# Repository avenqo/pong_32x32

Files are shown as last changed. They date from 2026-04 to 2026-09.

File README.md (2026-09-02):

## PöNG 32x32

**PöNG 32x32** is a project that serves as a platform for implementing various games.

The key components include:

- ESP32 controller
- A display based on a 32 × 32 RGB LED matrix,
- Two joysticks for player input,
- Multiple displays,
- A matrix display for showing game status information,
- A 16×2 LCD display with a rotary encoder for navigating the system menu.

Additionally, an SD card reader is integrated, which can be used, for example, to display graphics.

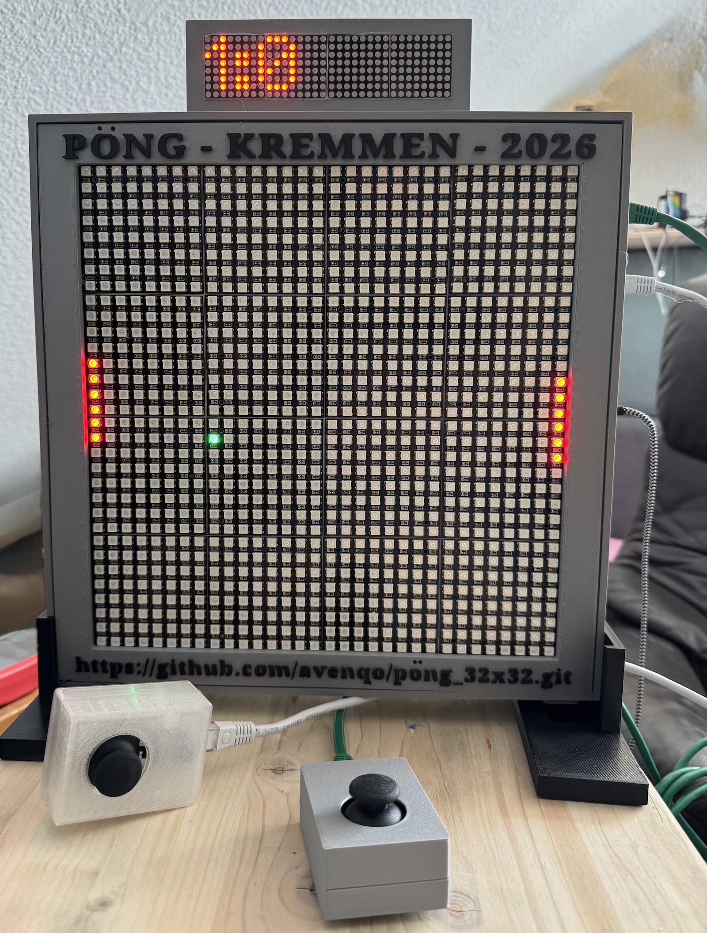
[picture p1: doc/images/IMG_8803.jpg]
Pöng32 Optional


The project consists of documentation for:

- [Hardware](doc/hardware.md),
- 3D models for the [Casing](doc/casing.md) and individual components,
- The actual [Software](doc/software.md), as well as several smaller test programs.

Inspired by the classic game Pong, I implemented a similar game to demonstrate the capabilities of the platform - **PöNG 32x32**.

### Game Operating Instructions

After power-on the device shows a short `START` splash and then runs in
*demo mode*: both paddles are controlled by the built-in AI, so the machine
plays against itself.

Switch between demo and a real match with the rotary encoder:

- turn the encoder while the menu shows `Mode`, or
- give the encoder a medium press (about a second).

Turning back to `Mode` (or another medium press) ends the match and returns to
demo mode. Holding the encoder long **twice within 4 seconds** restarts the
device (the first long press only shows a confirmation).

The system menu is opened with a short encoder press, which cycles through
`Mode`, `Delay`, `Volume`, `Brightness`, `Win at`, `Accel`, `Color`. Turning the
encoder changes the selected value:

- `Delay` – main-loop period in milliseconds (12–120); a smaller value makes the
  whole game faster.
- `Win at` – goals needed to win a match: `3`, `5` or `10` (default `5`).
- `Accel` – how strongly the ball speeds up during a rally: `OFF` or `1`–`3`
  (gentle … strong, default `2`).

### Game Rules

The playfield is the full 32 × 32 matrix. Each player owns one 6‑pixel paddle on
their edge (left / right). The score is shown on the 8‑digit display as
`left:right`.

Every rally runs through the same steps:

1. **Countdown** – `3 · 2 · 1` appears on the matrix, one beep per number. Both
   players may already move their paddles into position.
2. **Serve** – the ball starts near the centre with a random vertical position,
   a random vertical speed and a random left/right direction, together with a
   short "go" sound.
3. **Play**
   - The ball bounces off the top and bottom walls.
   - When it hits a paddle it bounces back; the point of impact sets the new
     vertical angle (near the centre → shallow, near the edge → steep). A dead
     centre hit still gets a slight up or down component, so a rally never locks
     into a purely horizontal exchange.
   - The ball speeds up over the course of a rally – up to about four times the
     serve speed – and drops back to the slow serve speed on the next point. How
     fast it ramps (or whether it ramps at all) is set by the `Accel` menu.
   - The ball always travels a little slower than the paddles and leaves a short
     fading trail.
4. **Goal** – if the ball gets past a paddle and reaches that edge, the opponent
   scores one point. `TOOOR!` is shown briefly, then the next countdown starts.
5. **Match end** – as soon as one side reaches the `Win at` target (3 / 5 / 10,
   default 5) the match is over: a short fanfare plays and a ~6 second victory
   animation runs on the matrix – a gold wipe sweeps in from the winner's edge,
   followed by coloured firework bursts while that edge keeps glowing. A fresh
   match then starts automatically, so demo mode also keeps cycling through
   complete matches with the full celebration.

**Paddle control:** the paddle follows the joystick – the further the stick is
pushed, the faster the paddle moves (up to 3 pixels per frame). In demo mode
both paddles are moved by the AI, which tracks the ball but keeps aiming a few
pixels off centre (re-rolled continuously) and hesitates now and then, so it
returns the ball at varying angles and misses often enough to keep the demo
lively.

A running match can also be abandoned at any time by turning the encoder back to
`Mode` (or a medium press), which returns the device to demo mode.

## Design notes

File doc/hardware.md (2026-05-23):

## Hardware

I purchased most of the components from AliExpress.

[The wiring is described here.](../hardware/wiring.md) 

The following table provides an overview of the used components.

### Bill of Material

| Component | Number | Price per Item|
|:--- |:---:| ---:|
| ESP32 			| 1 	| $5 |
| Speaker 3W 		| 1 | $2 |
| DFPlayer 				| 1 | $2 |
| SD-Card-Reader 		| 1 | $1 |
| SD-Cards 				| 2 | $4 |
| Joystick KY-023 				| 2 | $2 |
| Encoder KY-040 				| 1 | $2 |
| LCD 1602 (HD44780) with PCF8574 I2C adapter	| 1 | $2 |
| Max7219, 4-in-1 LED Dot-Matrix-Display 				| 1 | $3 |
| 8x8 Smart RGB LED NeoPixel Square 				| 16 | $2 |
| Power Supply 5V/5A 				| 1 | $5 |
| Ethernet Connectors 				| 2 | $1 |
| Ethernet Patch Cable 				| 2 | $1 |

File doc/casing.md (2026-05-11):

## Casing

The casing consists of several parts. All parts were printed with 15% infill.

I placed the individual 8x8 RGB matrix elements on a flat surface, bonded them together with hot glue, and then reinforced the assembly by gluing a hardboard backing to the rear.
The entire assembly can then be glued into the frame.

### Frame
The frame is positioned inside the casing. 
Here, the LED matrix is bonded—glued into the housing—and screwed in place. When I say "screwed in," I am referring to the use of heat-set inserts, which are embedded into the plastic using a soldering iron.

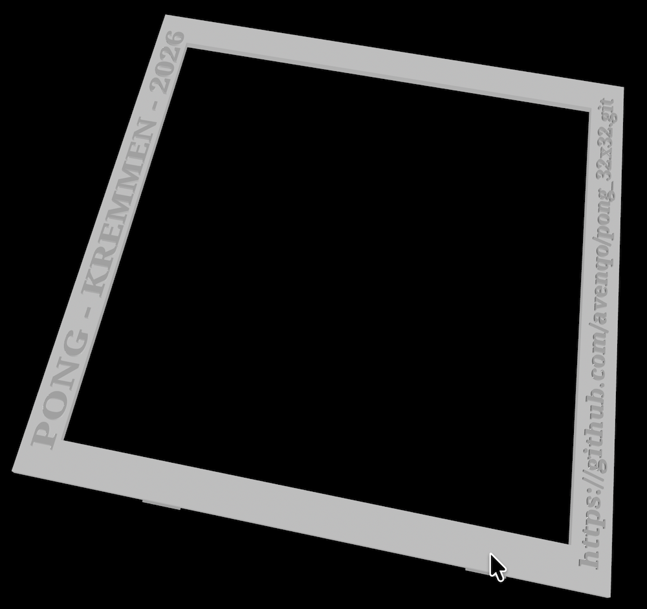
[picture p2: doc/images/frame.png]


### Casing
The individual components are screwed or glued into the housing and wired.

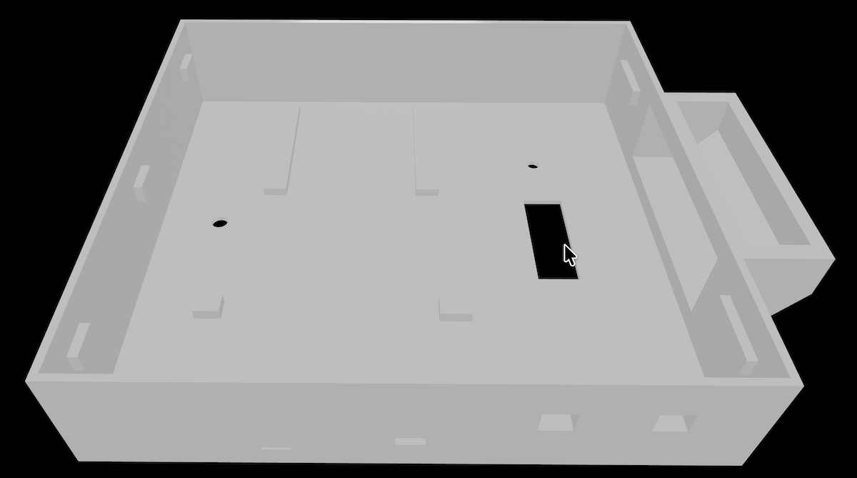
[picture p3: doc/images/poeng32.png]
Casing


### Ethernet Clips
The casing features Ethernet ports to which the joysticks are connected using standard Ethernet patch cables.
Therefore, if you are connecting two joysticks, you will need four of these clips (two inside the main casing, and one inside each of the respective joystick housings).

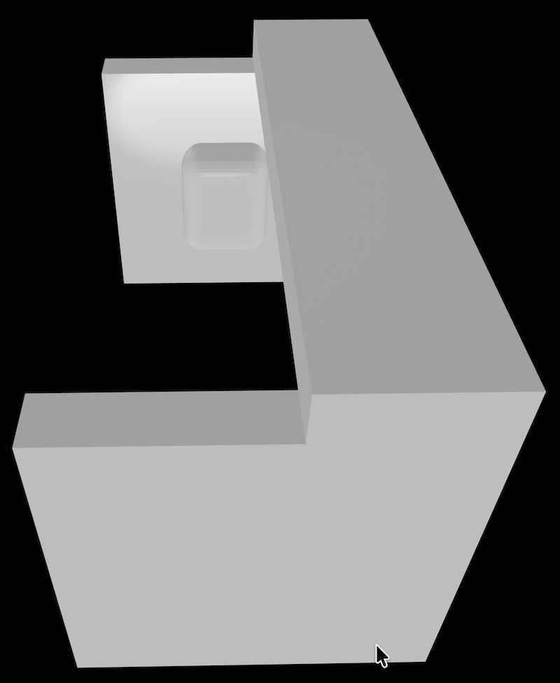
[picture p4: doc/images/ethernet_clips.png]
Clips for Ethernet Ports

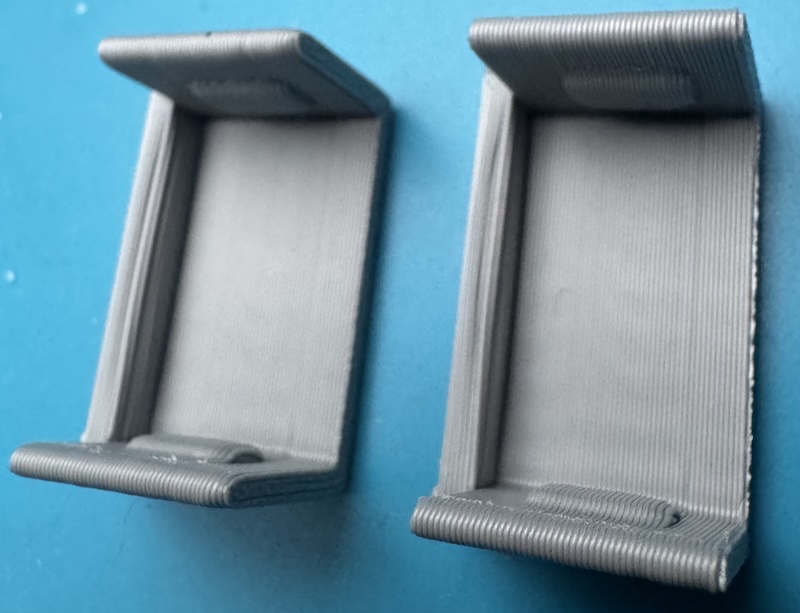
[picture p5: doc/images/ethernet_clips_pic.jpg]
Clips for Ethernet Ports


### Stand
The stand allows the game unit to be set up securely without the risk of tipping over.
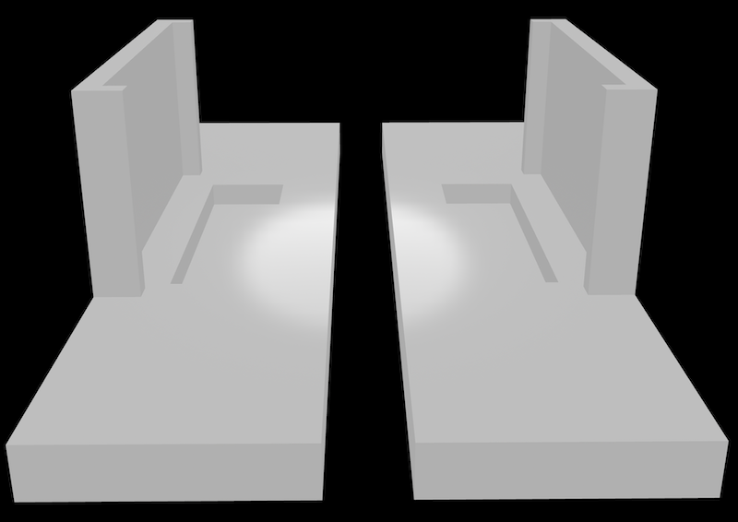
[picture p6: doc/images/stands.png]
Stand


### Joysticks
The joysticks are glued into these housings (two are required), and the housings are then screwed shut.

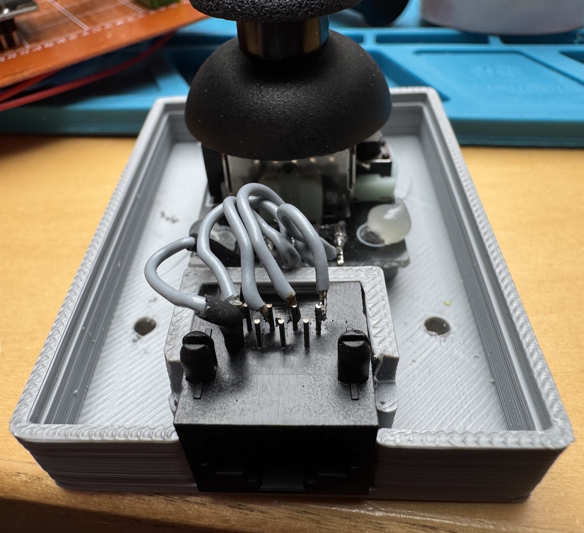
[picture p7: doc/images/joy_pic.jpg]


Here, too, a single Ethernet clip is required for each unit to secure the Ethernet jack in place.

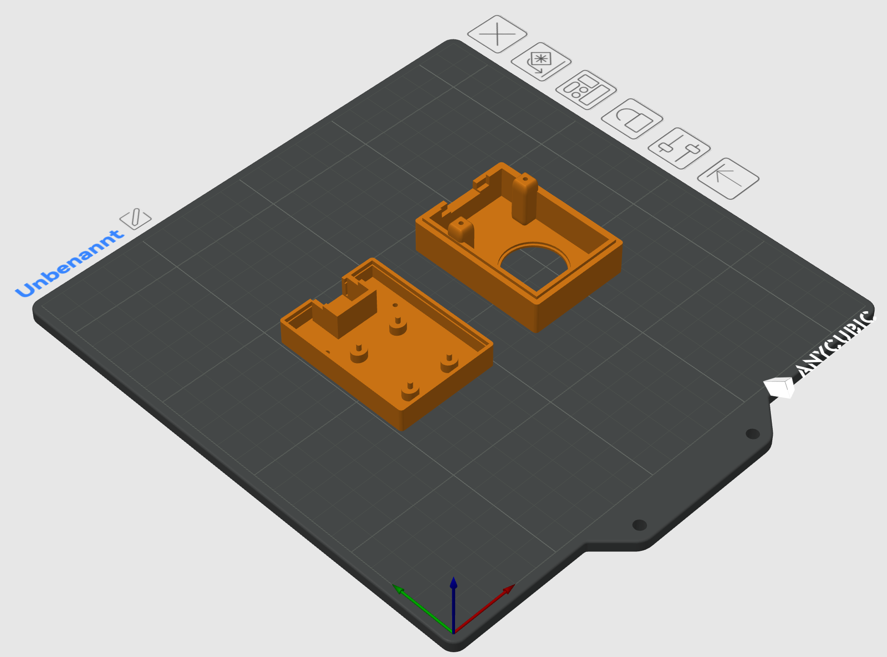
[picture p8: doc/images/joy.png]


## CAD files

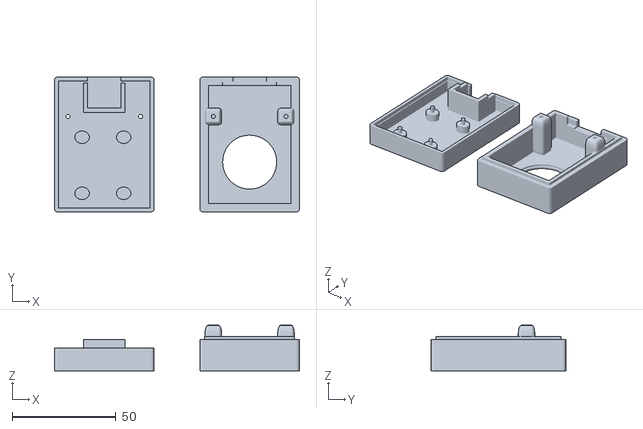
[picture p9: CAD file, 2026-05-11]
housing/Joystick-Housing-Small.stl
118.0 x 65.0 x 22.0

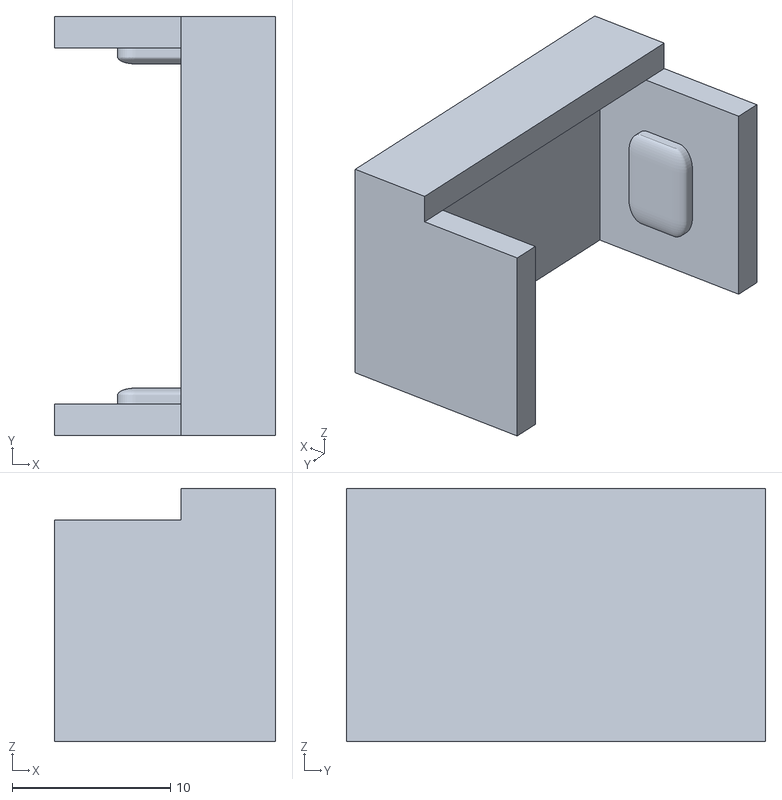
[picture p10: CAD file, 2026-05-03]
housing/Ethernet-Clips.stl
14.0 x 26.5 x 16.0

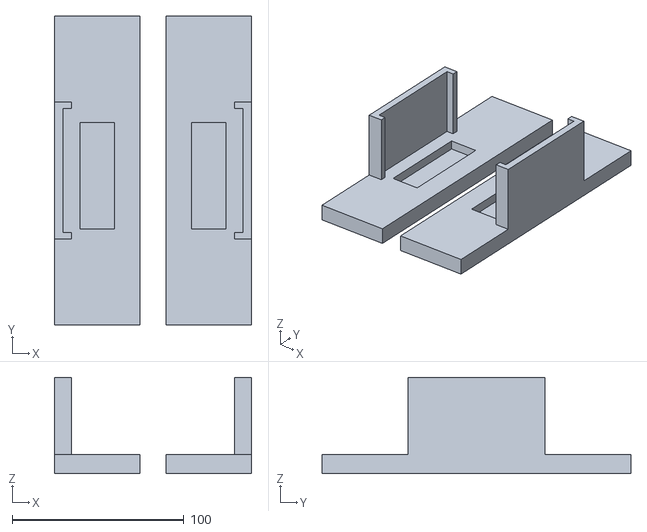
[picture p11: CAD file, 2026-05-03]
housing/Poeng32-Holder-2.stl
115.0 x 180.0 x 56.0

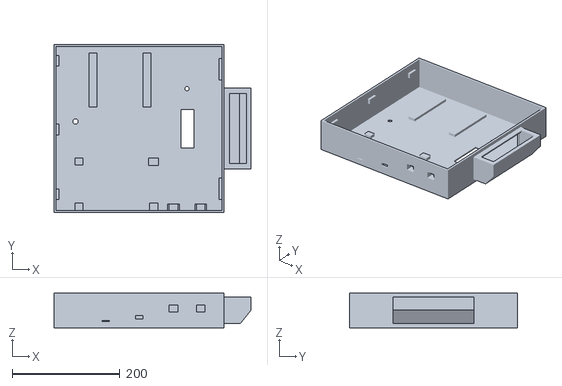
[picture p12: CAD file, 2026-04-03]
housing/Poeng_2026.stl
366.0 x 312.0 x 65.0

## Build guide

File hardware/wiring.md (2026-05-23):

# Hardware Wiring
The hardware is outlined below. Please note that these are **only sketches** showing the correct pin wiring according to the software configuration. 

Plugs, sockets, or other connectors are not depicted.

The power supply is not part of the sketches.

## LCD & Encoder
LCD displays and rotary encoders are used to adjust various settings via a menu, such as playback speed.

It reacts on rotation move (hopping throght the menu options) as well as menu seletion (push knob). 

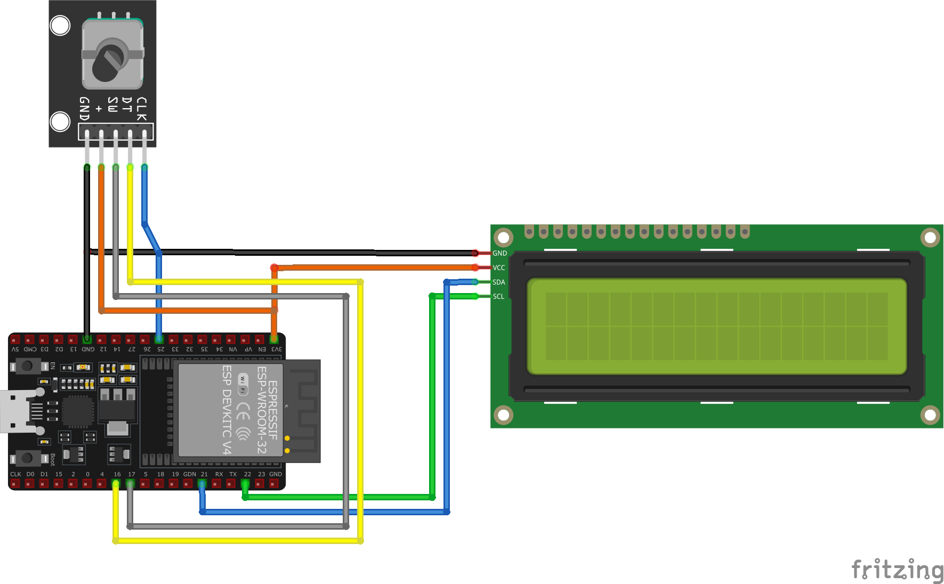
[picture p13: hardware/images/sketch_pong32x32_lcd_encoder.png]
LCD and Encoder


## Audio (MP3-Player)
The MP3 player is used to generate gameplay sounds. The card inserted in it contains the required audio files. However, mapping the numbers in the code to the corresponding sound files can be tricky. In each case, it must be verified whether the specified numbers actually correspond to the desired sounds.

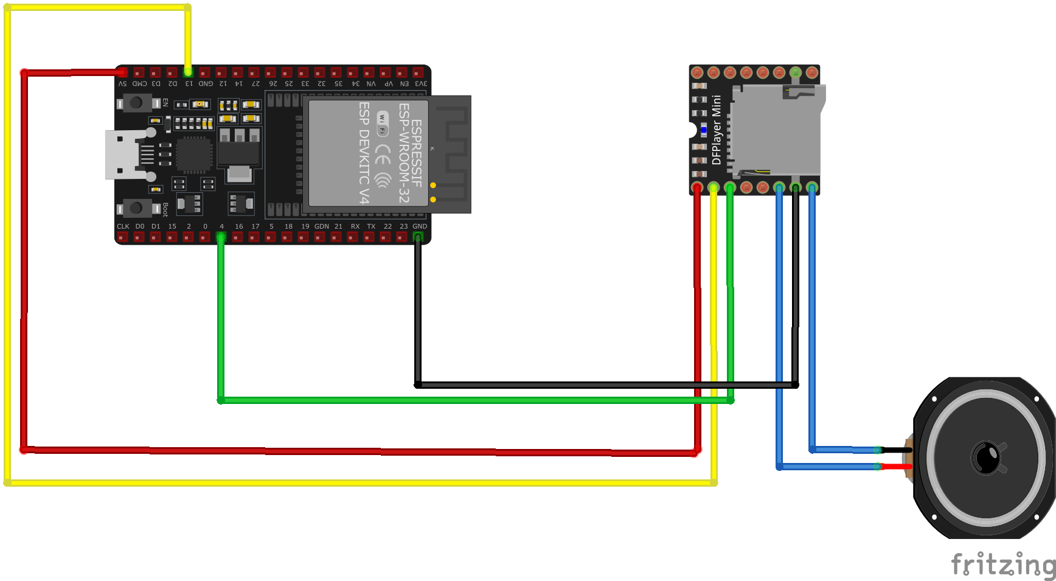
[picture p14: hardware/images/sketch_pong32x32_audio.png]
Audio Audio (MP3-Player)


## Joysticks
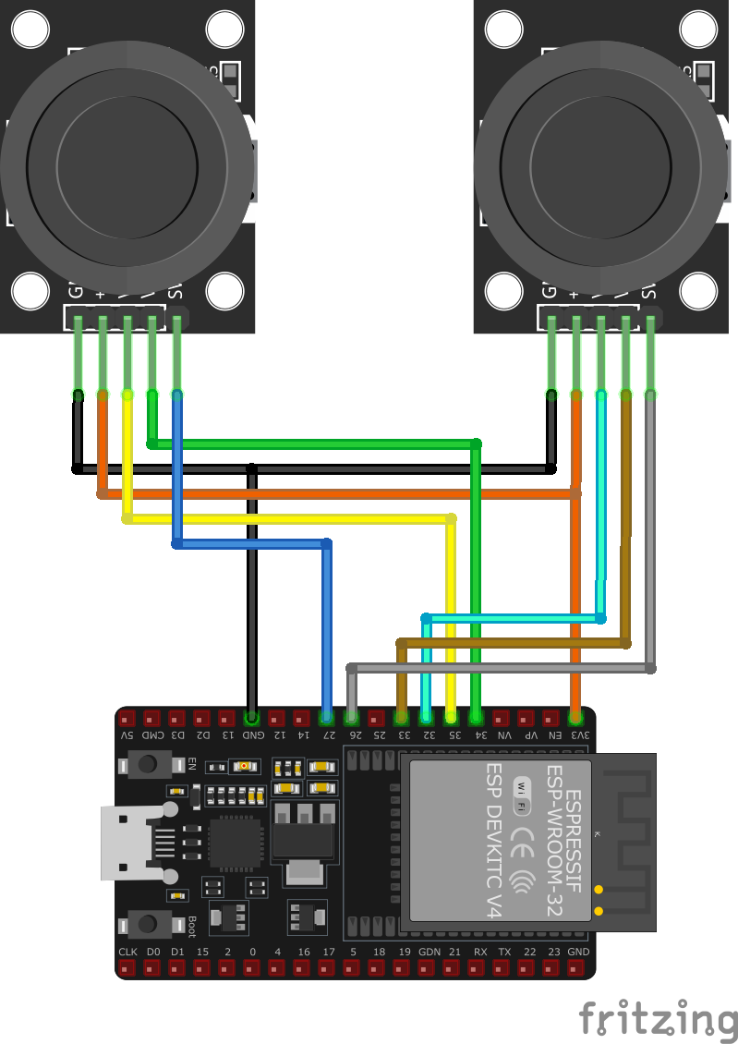
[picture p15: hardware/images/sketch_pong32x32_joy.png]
Joysticks


## LED Matrix
There are two LED matrices: an upper one, which displays the score, for example, and a lower one, which serves as the main screen. For simplicity, the diagram only shows 16 NeoPixel matrix elements as an example. Each of these elements must be connected in series, with the Pin Out of the previous element connected to the Pin In of the next.
Note: It is important to mention that NeoPixel matrix elements have a **relatively high power consumption** of appx. 3,5 Watt per element (when brightnes is set to 100%). Consequently, attention must be paid to the diameter of the power supply wiring. For currents of 10 amperes, a cross-sectional area of at least 1.5 square millimeters is recommended. Furthermore, it is advisable to include a **fuse** in the power supply circuit.

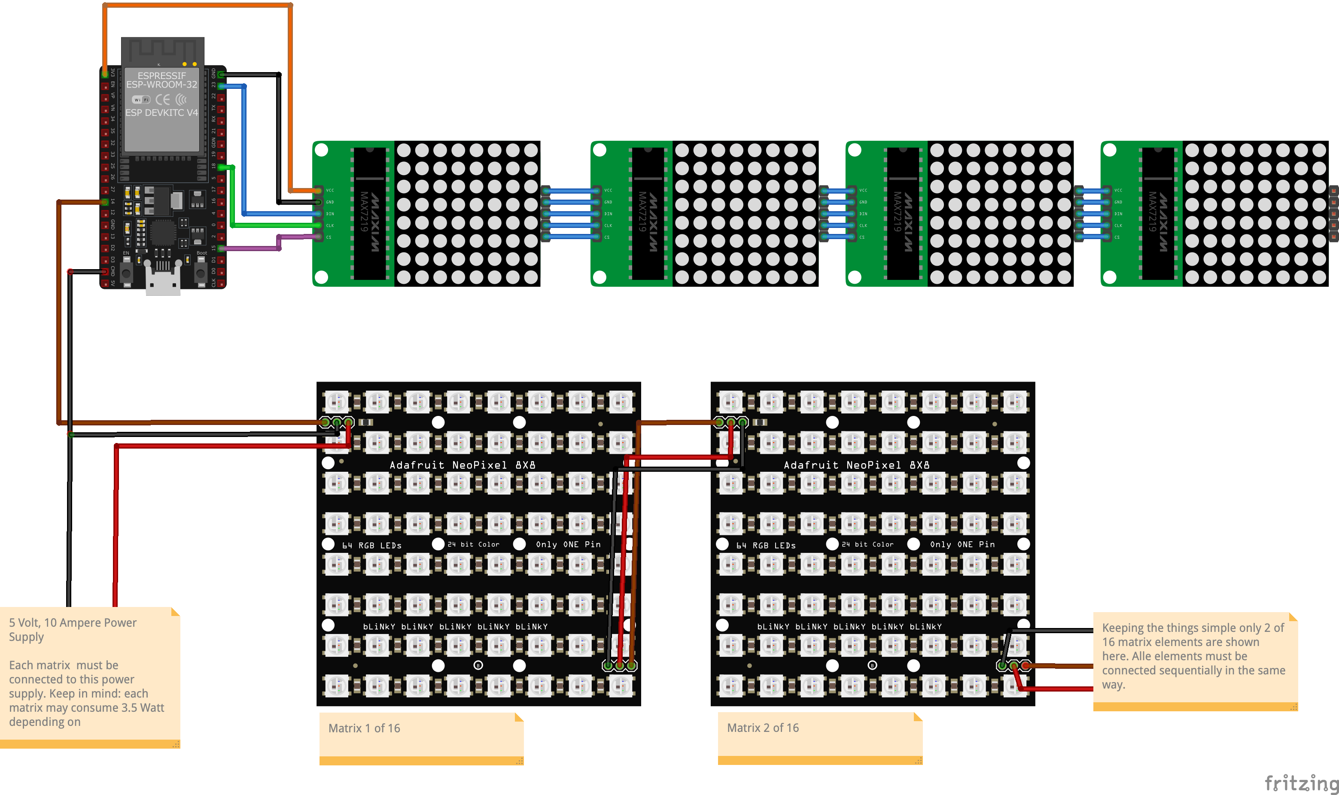
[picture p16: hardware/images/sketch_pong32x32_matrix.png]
LED Matrix


## SD Card
The SD card reader is intended to display animated graphics. However, this feature has not yet been implemented.

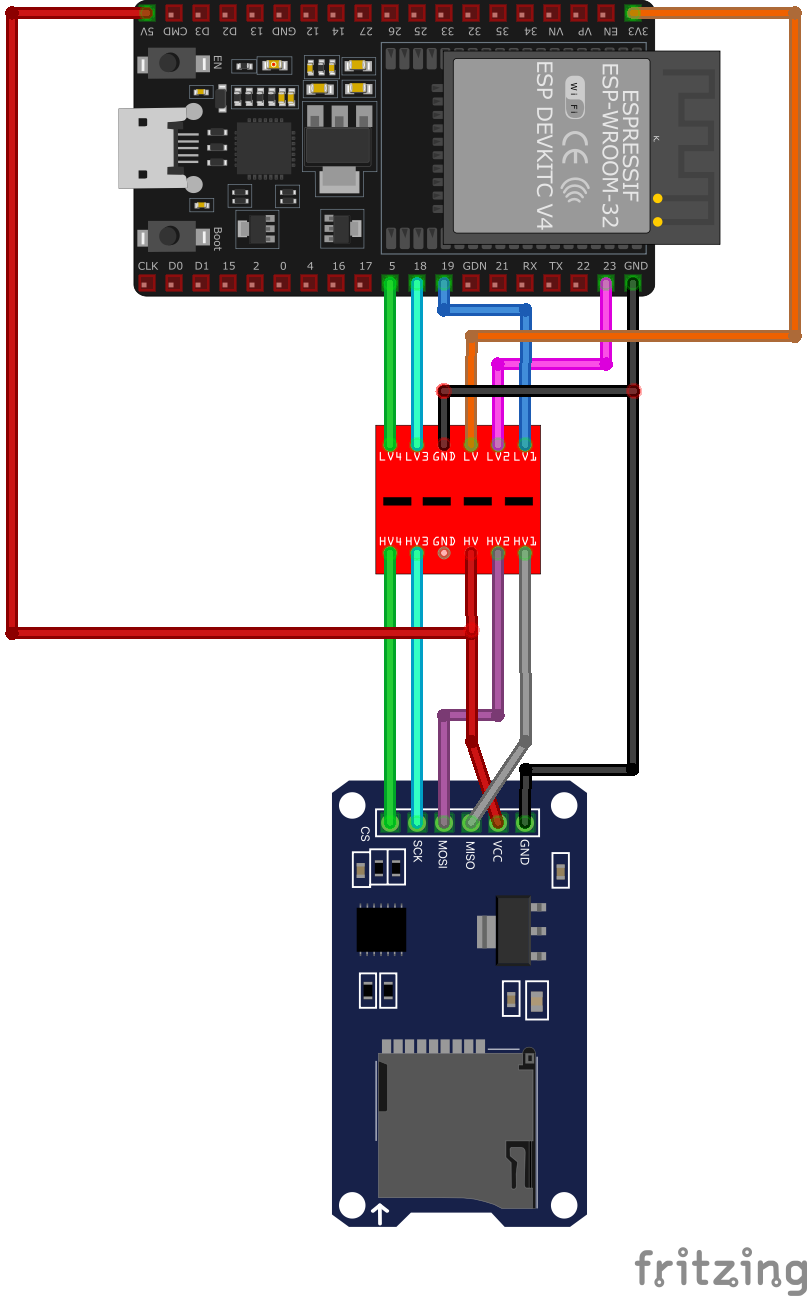
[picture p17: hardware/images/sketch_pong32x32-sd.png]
SD Card Reader


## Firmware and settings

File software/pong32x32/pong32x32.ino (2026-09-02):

#include <LiquidCrystal_I2C.h>
#include <Encoder.h>
#include <LedControl.h>
#include "RotaryEncoder.h"
#include "Joystick.h"
#include "LCDDisplay.h"
#include "MAX7219Display.h"
#include "SdCard.h"
#include "Matrix32x32.h"
#include "pong.h"
#include "DFPlayer.h"
#include "Global.h"

#define DEBUG_PONG

// Pins
const int encClkPin = 25, encDtPin = 16, encSwPin = 17;
const int maxClkPin = 18, maxDinPin = 23, maxCsPin = 15;
const int joy1VrxPin = 35, joy1VryPin = 34, joy1SwPin = 27;
const int joy2VrxPin = 32, joy2VryPin = 33, joy2SwPin = 26;

// Instanzen
RotaryEncoder* encoder;
Joystick* joy1;
Joystick* joy2;
LCDDisplay* lcd;
MAX7219Display* maxDisplay;
SdCard* sdcard;
Log* logg;
Matrix32x32* matrix;
Pong* pong;
DFPlayer* player;


// --- Menu Items ---
enum MenuItem { MODE, // DEMO, GAME etc.
                SPEED,
                VOLUME,
                BRIGHTNESS,
                WINSCORE,
                ACCEL,
                COLOR };
MenuItem currentMenu = MODE;
MenuSetup menu;


// --- Loop Variables ---

int MAX = 32;
int x = 0;
int y = 0;
int num = 0;

unsigned int loopCntMillis = millis();
// Never let the loop period reach 0 (would make the ball uncontrollable).
unsigned int loopTimeLimit = constrain(menu.speedValue, MIN_LOOP_MS, MAX_LOOP_MS);
StateItem lastSystemState = START;

// ---- Encoder & Menu Selection----

void onEncoderRotation(int direction) {
  logg->info("onEncoderRotation()");
 
  switch (currentMenu) {
    case MODE:
      if (systemState == DEMO) {
         switchState(GAME);
      } else {
         switchState(DEMO);
      }
      
      break;
    case SPEED:
      // speedValue is the loop *delay* in ms, so turning clockwise (direction > 0)
      // must make it smaller = faster. Kept inside [MIN_LOOP_MS, MAX_LOOP_MS].
      menu.speedValue = constrain((int)menu.speedValue - direction * SPEED_STEP,
                                  MIN_LOOP_MS, MAX_LOOP_MS);
      loopTimeLimit = menu.speedValue;
      player->onHitRightRacket();
      break;
    case VOLUME:
      menu.volumeValue = constrain(menu.volumeValue + direction, 0, 30);
      player->setVolume(menu.volumeValue);
      delay(300);  // without delay -> there is the chance to crash
      // just to gear the difference
      player->onHitLeftRacket();
      break;
    case BRIGHTNESS:
      menu.brightnessValue = constrain(menu.brightnessValue + direction, 0, 255);

      matrix->setBrightness(menu.brightnessValue);
      matrix->allOff();
      matrix->drawMemory();
      player->onHitRightRacket();

      break;
    case WINSCORE:
      // cycle through the three allowed targets 3 / 5 / 10
      if (direction > 0)
        menu.winScore = (menu.winScore < 5) ? 5 : 10;
      else
        menu.winScore = (menu.winScore > 5) ? 5 : 3;
      pong->setWinScore(menu.winScore);
      player->onHitLeftRacket();
      break;
    case ACCEL:
      // 0 = off, 1..3 = gentle..strong rally speed-up
      menu.accelValue = constrain(menu.accelValue + direction, 0, 3);
      pong->setAccel(menu.accelValue);
      player->onHitLeftRacket();
      break;
    case COLOR:
      menu.colorValue = constrain(menu.colorValue + direction, 1, 3);
      break;
  }
  updateMenuDisplay();
}


void updateMenuDisplay() {
  char buffer[17];
  lcd->clear();

  switch (currentMenu) {
     case MODE:
      snprintf(buffer, sizeof(buffer), "Mode: %s", stateStrings[systemState]);
      lcd->showText(0, buffer);
      break;
    case SPEED:
      // Show it as what it is: the per-frame delay in ms (smaller = faster).
      snprintf(buffer, sizeof(buffer), "Delay: %3u ms", menu.speedValue);
      lcd->showText(0, buffer);
      break;
    case VOLUME:
      snprintf(buffer, sizeof(buffer), "Volume: %3u", menu.volumeValue);
      lcd->showText(0, buffer);
      break;
    case BRIGHTNESS:
      snprintf(buffer, sizeof(buffer), "Brightness: %3u", menu.brightnessValue);
      lcd->showText(0, buffer);
      break;
    case WINSCORE:
      snprintf(buffer, sizeof(buffer), "Win at: %2u", menu.winScore);
      lcd->showText(0, buffer);
      break;
    case ACCEL:
      if (menu.accelValue == 0)
        snprintf(buffer, sizeof(buffer), "Accel: OFF");
      else
        snprintf(buffer, sizeof(buffer), "Accel: %u", menu.accelValue);
      lcd->showText(0, buffer);
      break;
    case COLOR:
      snprintf(buffer, sizeof(buffer), "Color: %s",
               menu.colorValue == 1 ? "Farbe 1" : menu.colorValue == 2 ? "Farbe 2"
                                                                       : "Farbe 3");
      lcd->showText(0, buffer);
      break;
  }
}



void onEncoderButtonPressShort() {
  logg->info("onEncoderButtonPressShort()");

  // 5 menu items (MODE..COLOR) - the old "% 4" made COLOR unreachable.
  currentMenu = static_cast<MenuItem>((currentMenu + 1) % (COLOR + 1));
  updateMenuDisplay();
}


void onEncoderButtonPressMedium() {
  logg->info("onEncoderButtonPressMedium()");

  if (systemState == DEMO) {
    switchState(GAME);
  } else if (systemState == GAME) {
    switchState(DEMO);
  }
}


void onEncoderButtonPressLong() {
  logg->info("onEncoderButtonPressLong()");

  // Two-step confirm: the first long press only arms the restart, a second
  // long press within 4 s actually does it. Prevents an accidental reboot
  // mid-game.
  static unsigned long armedAt = 0;
  if (armedAt != 0 && (millis() - armedAt) < 4000) {
    lcd->clear();
    lcd->showText(0, "Restarte Poeng");
    delay(400);
    ESP.restart();
  } else {
    armedAt = millis();
    lcd->clear();
    lcd->showText(0, "Neustart? Taste");
    lcd->showText(1, "lang halten");
  }
}

// --- Joystick Button pressed ---

void onJoystickButtonPress_left(byte buttonByte) {
  logg->info("onJoystickButtonPress_left()");
  static char maxMsg[9];
  snprintf(maxMsg, 9, "A Push");
  maxDisplay->showMessage(maxMsg);
}


void onJoystickButtonPress_right(byte buttonByte) {
  logg->info("onJoystickButtonPress_right()");
  static char maxMsg[9];
  snprintf(maxMsg, 9, "B Push");
  maxDisplay->showMessage(maxMsg);
}

// ------------- Switch State ---------------

void switchState(StateItem newState) {
  boolean allowStateChange = false;

  if (systemState == START) {
    if (newState == DEMO) {
      allowStateChange = true;
    }
  } else if (systemState == DEMO) {
    if (newState == GAME) {
      allowStateChange = true;
    }

  } else if (systemState == GAME) {
    if (newState == DEMO) {
      allowStateChange = true;
    }
  } else {
    maxDisplay->showMessage("E9247");
  }

  if (allowStateChange) {
    systemState = newState;
    lcd->showText(0, "Change State");
    lcd->showText(1, stateStrings[systemState]);
    delay(500);
    logg->info("switch to new state", stateStrings[systemState]);

     if (systemState == DEMO) 
      pong->enableDemoMode();
     else if (newState == GAME) 
      pong->disableDemoMode();
  }
}

// =============== Setup() ==================

void setup() {

  delay(500);
  Serial.begin(115200);
  delay(500);
  logg = new Log("Main");
  logg->info("=== Start PÖNG 32x32 ===");

  // Seed the RNG so ball serves and the demo AI are not identical every boot.
  // (ADC noise on the joystick inputs + micros() at power-on = enough entropy.)
  randomSeed(micros() ^ (analogRead(joy1VrxPin) << 3) ^ (analogRead(joy2VrxPin) << 7));

  // clear all data
  matrix = new Matrix32x32(menu.brightnessValue);
  matrix->allOff();
  matrix->drawMemory();

  lcd = new LCDDisplay(0x27);  // or 0x3F
  lcd->showText(0, "PöNG 32x32");

  maxDisplay = new MAX7219Display(maxClkPin, maxDinPin, maxCsPin);
  maxDisplay->showMessage("P\xD6NG!");  // PöNG

  delay(500);

  encoder = new RotaryEncoder(encClkPin, encDtPin, encSwPin);
  joy1 = new Joystick(joy1VrxPin, joy1VryPin, joy1SwPin);
  joy2 = new Joystick(joy2VrxPin, joy2VryPin, joy2SwPin);

  sdcard = new SdCard();

  player = new DFPlayer();
  player->init();
  player->setVolume(menu.volumeValue);

  pong = new Pong(maxDisplay, player);
  pong->setWinScore(menu.winScore);
  pong->setAccel(menu.accelValue);

  // Callbacks registrieren
  encoder->onRotation(onEncoderRotation);
  encoder->onButtonShortPress(onEncoderButtonPressShort);
  encoder->onButtonMediumPress(onEncoderButtonPressMedium);
  encoder->onButtonLongPress(onEncoderButtonPressLong);
  logg->info("Callbacks for encoder are registered");

  //joy1->onMovement(onJoystickMovement_left);
  joy1->onButtonPress(onJoystickButtonPress_left);
  //joy2->onMovement(onJoystickMovement_right);
  joy2->onButtonPress(onJoystickButtonPress_right);

  maxDisplay->showMessage("Ready");

  // at this point we are still in START mode
  pong->enableDemoMode();
}

// =============== loop() ==================

void loop() {

  // --- crash tracing -------------------------------------------------------
  // Prints a heartbeat with the free heap once a second. If the board freezes,
  // the last line pins down when it died; a steadily falling heap points at a
  // leak, a sudden stop with plenty of heap points at power / peripheral lock-up.
  static unsigned long hbTimer = 0;
  if (millis() - hbTimer > 1000) {
    hbTimer = millis();
    Serial.printf("[hb] t=%lu state=%d heap=%u\n",
                  millis(), (int)systemState, ESP.getFreeHeap());
  }

  // handle menu adjustments
  encoder->update();

  // After Switch on keep the Start state running for 5 sec
  if (systemState == START) {
    maxDisplay->showMessage("START");
    if ((millis() - loopCntMillis) > 5000) {
      // switch to next status
      loopCntMillis = millis();
      switchState(DEMO);
    }
  }

  else if ((systemState == GAME) || (systemState == DEMO)) {

    // State switched? Starte Game!
    if (lastSystemState != systemState) {
      pong->startGame();
    }

    // Update the game
    static unsigned long timer = millis();
    if ((millis() - timer) > loopTimeLimit) {
      timer = millis();

      joy1->update();
      joy2->update();

      if (pong) {
        pong->loop(joy1, joy2);
      }

      // Repaint the matrix from the framebuffer, but never faster than
      // MIN_DRAW_MS: drawMemory() blocks with interrupts off for ~31 ms, so
      // calling it back-to-back starves the system and can freeze the board.
      static unsigned long drawTimer = millis();
      if ((millis() - drawTimer) >= MIN_DRAW_MS) {
        drawTimer = millis();
        matrix->drawMemory();
      }
    }
  } else {
    maxDisplay->showMessage("E9246");
  }

  lastSystemState = systemState;
}

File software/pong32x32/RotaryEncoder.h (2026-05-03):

#ifndef ROTARY_ENCODER_H
#define ROTARY_ENCODER_H

#include <Arduino.h>
#include <Encoder.h>
#include "log.h"

#define LONG_DURATION 6000
#define MEDIUM_DURATION 1000
#define SHORT_DURATION 50

class RotaryEncoder{
public:
    RotaryEncoder(int clkPin, int dtPin, int swPin);
    void onRotation(void (*callback)(int));

    // 50ms ... < 1 sec
    void onButtonShortPress(void (*callback)());
    // > 1 ... < 3 sec
    void onButtonMediumPress(void (*callback)());
    // > 6 sec
    void onButtonLongPress(void (*callback)());

    void update();

private:
    Log* logg;
  
    Encoder encoder;
    int swPin;
    long oldPosition = -999;
    int lastSwState = HIGH;
    int lastSwitchState = HIGH;
    
    unsigned long lastDebounceTime = 0;
    unsigned long debounceDelay = SHORT_DURATION;
    unsigned long pressStartTime; // Speichert den Zeitpunkt, wann der Button gedrückt wurde

    void (*rotationCallback)(int) = nullptr;

    void (*buttonCallbackShort)() = nullptr;
    void (*buttonCallbackMedium)() = nullptr;
    void (*buttonCallbackLong)() = nullptr;
};

#endif // ROTARY_ENCODER_H

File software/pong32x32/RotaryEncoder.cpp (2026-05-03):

#include "RotaryEncoder.h"

RotaryEncoder::RotaryEncoder(int clkPin, int dtPin, int swPin)
  : encoder(clkPin, dtPin), swPin(swPin) {
  pinMode(swPin, INPUT_PULLUP);
  logg = new Log("Encoder");
}

void RotaryEncoder::onRotation(void (*callback)(int)) {
  rotationCallback = callback;
}

void RotaryEncoder::onButtonShortPress(void (*callback)()) {
  buttonCallbackShort = callback;
}

void RotaryEncoder::onButtonMediumPress(void (*callback)()) {
  buttonCallbackMedium = callback;
}

void RotaryEncoder::onButtonLongPress(void (*callback)()) {
  buttonCallbackLong = callback;
}


void RotaryEncoder::update() {
  long newPosition = encoder.read() / 4; // some simple deboucing
  if (newPosition != oldPosition) {
    int direction = (newPosition > oldPosition) ? -1 : 1;
    oldPosition = newPosition;
    if (rotationCallback) {
      rotationCallback(direction);
    }
  }

  // fetch SW (with debouncing)
  int currentSwState = digitalRead(swPin);

  // Debounce-Logik
  if (currentSwState != lastSwitchState) {
    lastDebounceTime = millis();
  }

  // if State remains stable (afterh Debounce)
  if ((millis() - lastDebounceTime) > debounceDelay) {
    // Wenn der Zustand sich geändert hat
    if (currentSwState != lastSwState) {
      lastSwState = currentSwState;

      // Button pushed (HIGH->LOW)
      if (lastSwState == LOW) {
        pressStartTime = millis(); // Zeitpunkt des Drückens speichern
      }
      // Button released(LOW->HIGH)
      else {
        unsigned long pressDuration = millis() - pressStartTime;

        // Callbacks je nach Drückdauer aufrufen
        if (pressDuration >= LONG_DURATION && buttonCallbackLong) {
          buttonCallbackLong();
        }
        else if (pressDuration >= MEDIUM_DURATION && buttonCallbackMedium) {
          buttonCallbackMedium();
        }
        else if (pressDuration >= SHORT_DURATION && buttonCallbackShort) {
          buttonCallbackShort();
        }
      }
    }
  }
  lastSwitchState = currentSwState;
}

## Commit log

2026-04-03 housing added
    [Pong_2026-3.stl]
2026-05-03 first iteration with initial documentation
    [Ethernet-Clips.3mf, Ethernet-Clips.stl, Pong32-Holder-2.stl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]
2026-05-09 documentation of casing
    [Ethernet-Clips.3mf, Poeng32-Holder-2.stl, Poeng_2026.stl]
2026-05-11 documentation of casing 2
    [Joystick-Housing-Small.stl]
2026-05-23 hardware wiring added
    [sketch_pong32x32-sd.fzz, sketch_pong32x32_audio.fzz, sketch_pong32x32_joy.fzz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]
